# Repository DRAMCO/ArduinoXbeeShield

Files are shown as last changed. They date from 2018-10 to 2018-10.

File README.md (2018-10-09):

# Arduino Xbee Shield by [DRAMCO](www.dramco.be)

## Required Hardware

- Xbee module
- [Digi XBee interface board](https://www.digi.com/products/models/xbib-u-dev)
- Arduino Uno
- DRAMCO XBee Shield

## Getting Started Guide

1. Install [XCTU](https://www.digi.com/products/xbee-rf-solutions/xctu-software/xctu).
2. Connect the XBee module to the [Digi interface board](https://www.digi.com/products/models/xbib-u-dev)
3. Open XCTU and connect to the interface board
4. Configure the XBee module as required. For instance, set the `AP` parameter to API enabled with PPP.
5. Connect the XBee module to the shield
6. Connectthe shield to an Arduino UNO
7. Open your favourite Arduino IDE and download an XBee library. For example [this one](https://github.com/andrewrapp/xbee-arduino).
8. Start designing cool stuff!

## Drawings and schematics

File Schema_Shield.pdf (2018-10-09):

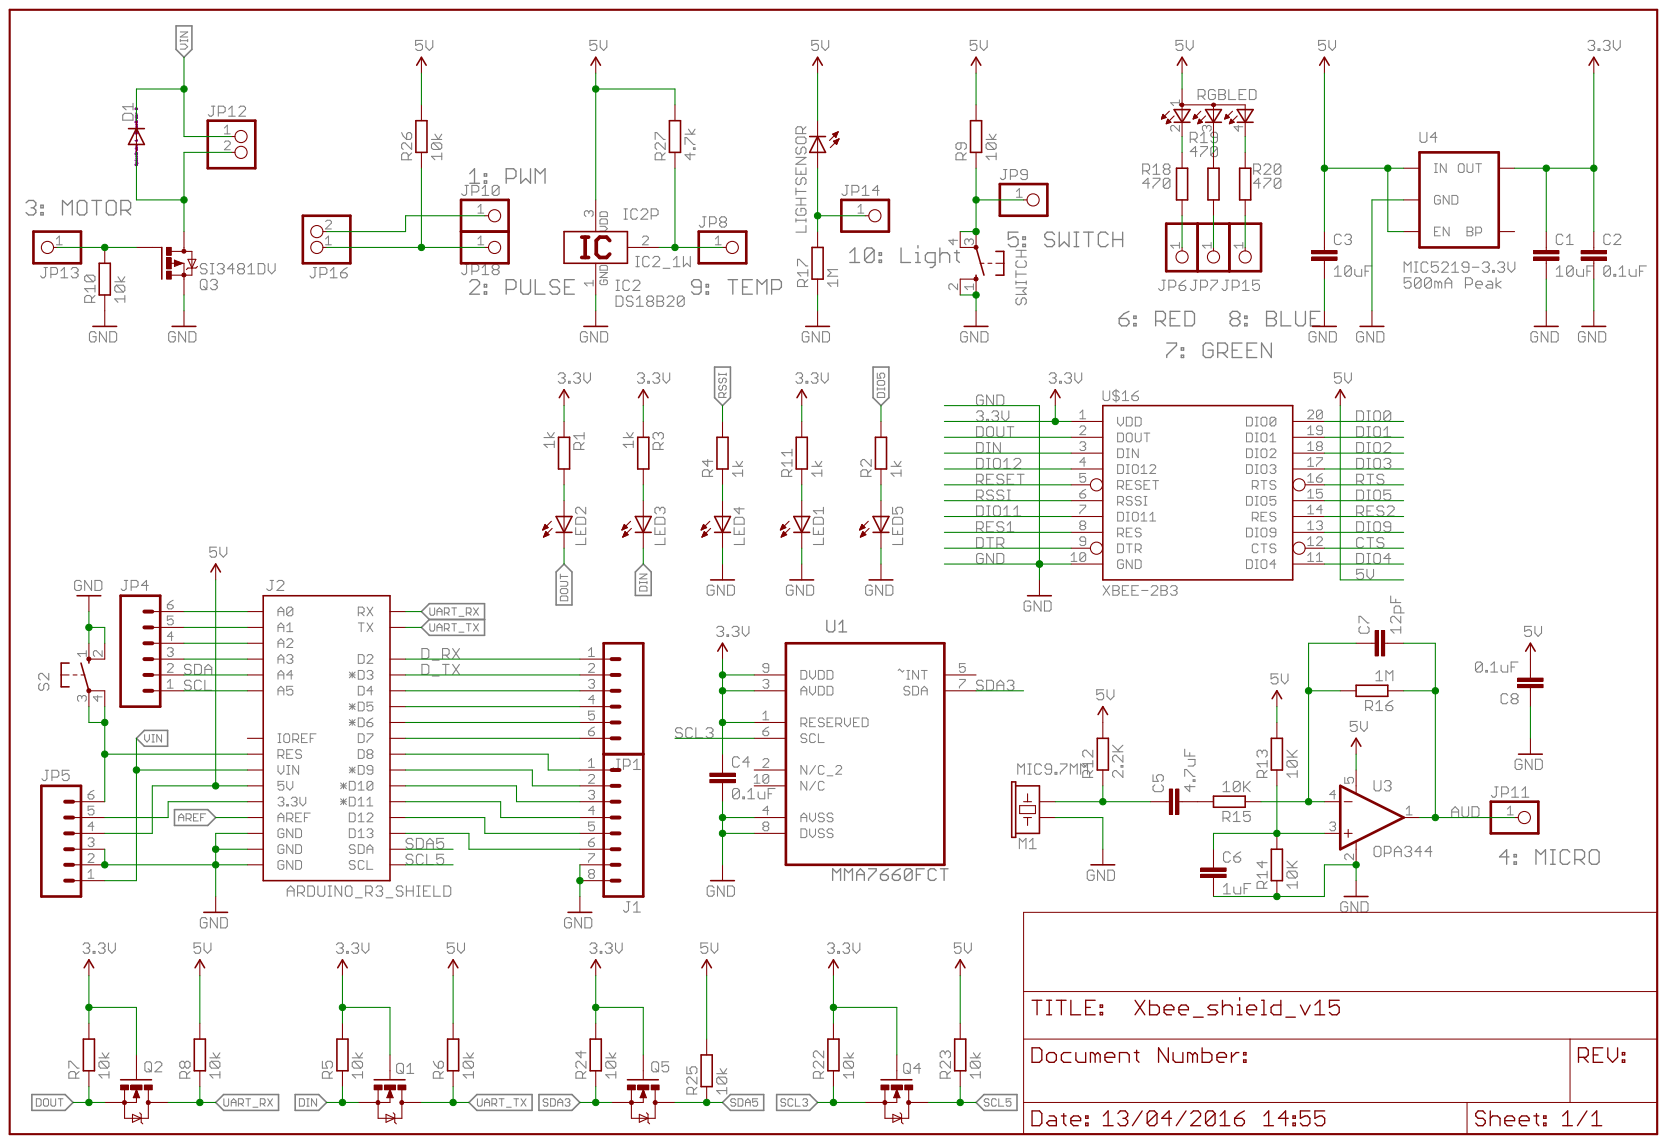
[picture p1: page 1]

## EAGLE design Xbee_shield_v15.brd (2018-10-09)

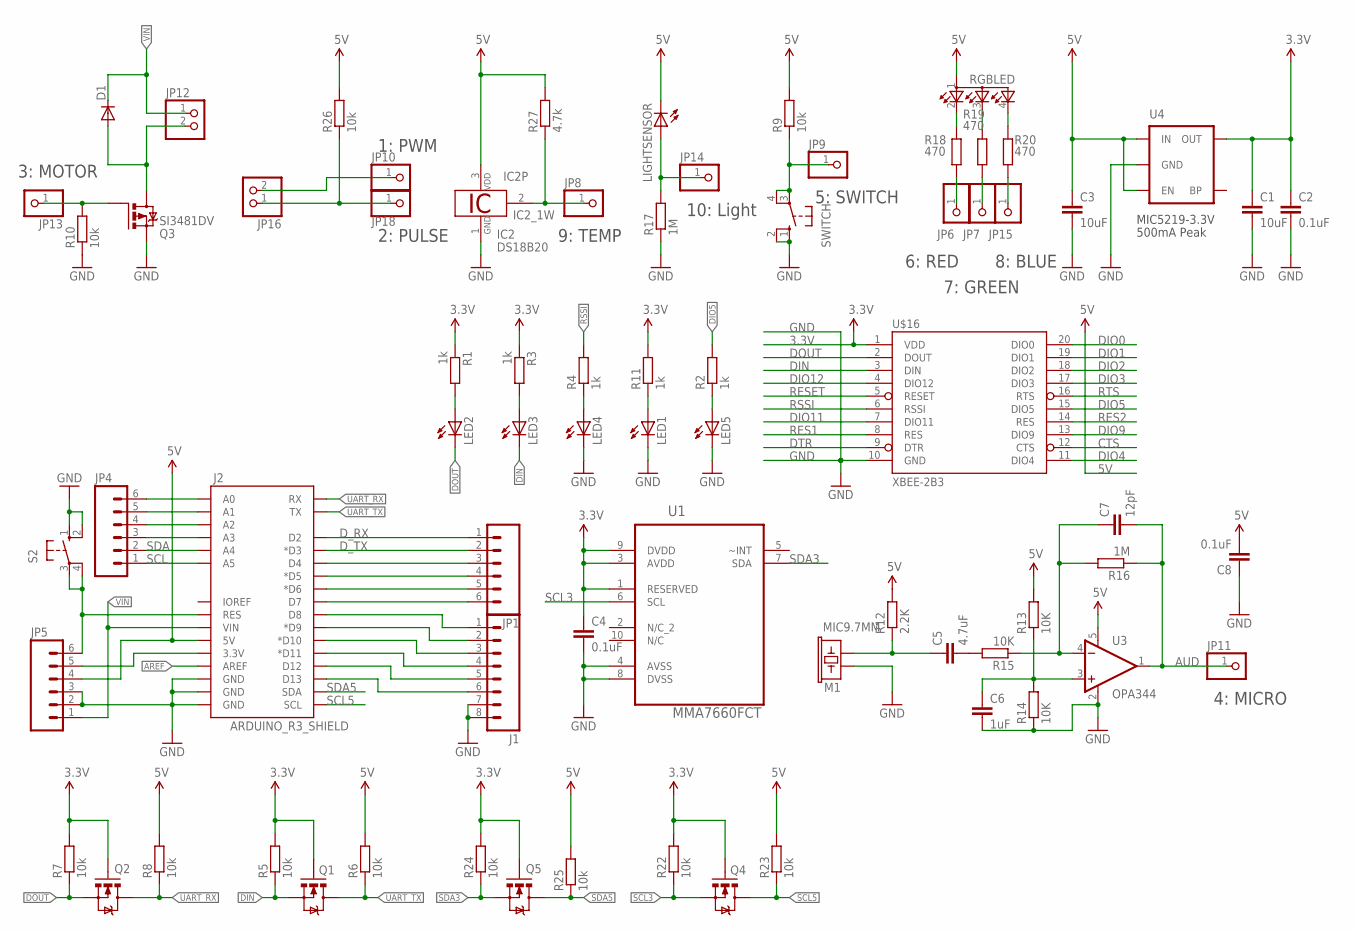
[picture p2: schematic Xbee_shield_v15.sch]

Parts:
C1, C3: 10uF; C0805
C2, C4, C8: 0.1uF; C0805
C5: 4.7uF; C0805
C6: 1uF; C0805
C7: 12pF; C0805
D1: DIODE-DO214AA; DO214AA
IC2: DS18B20; TO92-
J1: M08; 1X08_ROUND
J2: ARDUINO_R3_SHIELD; UNO_R3_SHIELD
JP1, JP4, JP5: M06SIP; 1X06
JP6, JP7, JP8, JP9, JP10, JP11, JP13, JP14, JP15, JP18: PINHD-1X1; 1X01
JP12, JP16: PINHD-1X2; 1X02
LED1, LED2, LED3, LED4, LED5: LEDCHIPLED_0805; CHIPLED_0805
LIGHTSENSOR: LED5MM
M1: MIC9.7MM; MIC-9.7MM
Q1, Q2, Q4, Q5: MOSFET-NCHANNELSMD; SOT23-3
Q3: SI3481DV; TSOP-6.PAC
R1, R2, R3, R4, R11: 1k; R0805
R5, R6, R7, R8, R9, R10, R22, R23, R24, R25, R26: 10k; R0805
R12: 2.2K; R0805
R13, R14, R15: 10K; R0805
R16, R17: 1M; R0805
R18, R19, R20: 470; R0805
R27: 4.7k; R0805
RGBLED: TOPLED-3; P-LCC-4-3
S2: 10-XX; B3F-10XX
SWITCH: 10-XX; B3F-10XX
U1: MMA7660FCT; DFN300X300X100-10N
U3: OPA344; SOT23-5
U4: V_REG_LDOSMD; SOT23-5
U$16: XBEE-2B3; XBEE-SMD

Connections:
3.3V: C1.1, C2.1, C4.1, Q1.1 (G), Q2.1 (G), Q4.1 (G), Q5.1 (G), R1.1, R3.1, R5.2, R7.2, R11.2, R22.2, R24.2, U1.1 (RESERVED), U1.3 (AVDD), U1.9 (DVDD), U4.5 (OUT), U$16.1 (VDD)
5V: C3.1, C8.2, IC2.3 (VDD), J2.5V, JP5.4, LIGHTSENSOR.K (C), R6.2, R8.2, R9.2, R12.2, R13.2, R23.2, R25.2, R26.2, R27.2, RGBLED.1 (A2), U3.5 (V+), U4.1 (IN), U4.3 (EN)
AREF: J2.AREF
AUD: C7.2, JP11.1, R16.1, U3.1 (OUT)
CTS: U$16.12 (CTS)
DIN: LED3.C, Q1.2 (S), R5.1, U$16.3 (DIN)
DIO0: U$16.20 (DIO0)
DIO1: U$16.19 (DIO1)
DIO2: U$16.18 (DIO2)
DIO3: U$16.17 (DIO3)
DIO4: U$16.11 (DIO4)
DIO5: R2.2, U$16.15 (DIO5)
DIO9: U$16.13 (DIO9)
DIO11: U$16.7 (DIO11)
DIO12: U$16.4 (DIO12)
DOUT: LED2.C, Q2.2 (S), R7.1, U$16.2 (DOUT)
DTR: U$16.9 (DTR)
D_RX: J2.D2, JP1.1
D_TX: J2.D3 (*D3), JP1.2
GND: C1.2, C2.2, C3.2, C4.2, C6.2, C8.1, IC2.1 (GND), J1.7, J1.8, J2.GND@0 (GND), J2.GND@1 (GND), J2.GND@2 (GND), JP5.2, JP5.3, LED1.C, LED4.C, LED5.C, M1.2, Q3.4 (S), R10.1, R14.1, R17.1, S2.1 (S), S2.2 (S1), SWITCH.1 (S), SWITCH.2 (S1), U1.4 (AVSS), U1.8 (DVSS), U3.2 (V-), U4.2 (GND), U$16.10 (GND)
unnamed: LED2.A, R1.2
unnamed: LED4.A, R4.1
unnamed: J1.6, J2.D13
unnamed: LED3.A, R3.2
unnamed: J2.A0, JP4.6
unnamed: J2.A1, JP4.5
unnamed: J2.A2, JP4.4
unnamed: J2.RES, JP5.6, S2.3, S2.4 (P1)
unnamed: JP9.1, R9.1, SWITCH.3, SWITCH.4 (P1)
unnamed: IC2.2 (1W), JP8.1, R27.1
unnamed: JP10.1, JP16.2
unnamed: C5.1, M1.1, R12.1
unnamed: C7.1, R15.1, R16.2, U3.4 (-IN)
unnamed: C5.2, R15.2
unnamed: C6.1, R13.1, R14.2, U3.3 (+IN)
unnamed: J1.1, J2.D8
unnamed: J1.2, J2.D9 (*D9)
unnamed: JP13.1, Q3.3 (G), R10.2
unnamed: D1.A, JP12.2, Q3.1 (D), Q3.2 (D), Q3.5 (D), Q3.6 (D)
unnamed: JP14.1, LIGHTSENSOR.A, R17.2
unnamed: J2.A3, JP4.3
unnamed: JP16.1, JP18.1, R26.1
unnamed: J2.3.3V, JP5.5
unnamed: R18.2, RGBLED.2 (CRED)
unnamed: R19.2, RGBLED.3 (CBLUE)
unnamed: R20.2, RGBLED.4 (CGREEN)
unnamed: JP6.1, R18.1
unnamed: J1.3, J2.D10 (*D10)
unnamed: JP7.1, R19.1
unnamed: JP15.1, R20.1
unnamed: LED1.A, R11.1
unnamed: J1.4, J2.D11 (*D11)
unnamed: J1.5, J2.D12
unnamed: LED5.A, R2.1
unnamed: J2.D4, JP1.3
unnamed: J2.D5 (*D5), JP1.4
unnamed: J2.D6 (*D6), JP1.5
unnamed: J2.D7, JP1.6
RES1: U$16.8 (RES)
RES2: U$16.14 (RES)
RESET: U$16.5 (RESET)
RSSI: R4.2, U$16.6 (RSSI)
RTS: U$16.16 (RTS)
SCL: J2.A5, JP4.1
SCL3: Q4.2 (S), R22.1, U1.6 (SCL)
SCL5: J2.SCL, Q4.3 (D), R23.1
SDA: J2.A4, JP4.2
SDA3: Q5.2 (S), R24.1, U1.7 (SDA)
SDA5: J2.SDA, Q5.3 (D), R25.1
UART_RX: J2.RX, Q2.3 (D), R8.1
UART_TX: J2.TX, Q1.3 (D), R6.1
VIN: D1.C, J2.VIN, JP5.1, JP12.1

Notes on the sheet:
500mA Peak
MIC5219-3.3V
1: PWM
2: PULSE
3: MOTOR
10: Light
5: SWITCH
6: RED
7: GREEN
8: BLUE
9: TEMP
4: MICRO

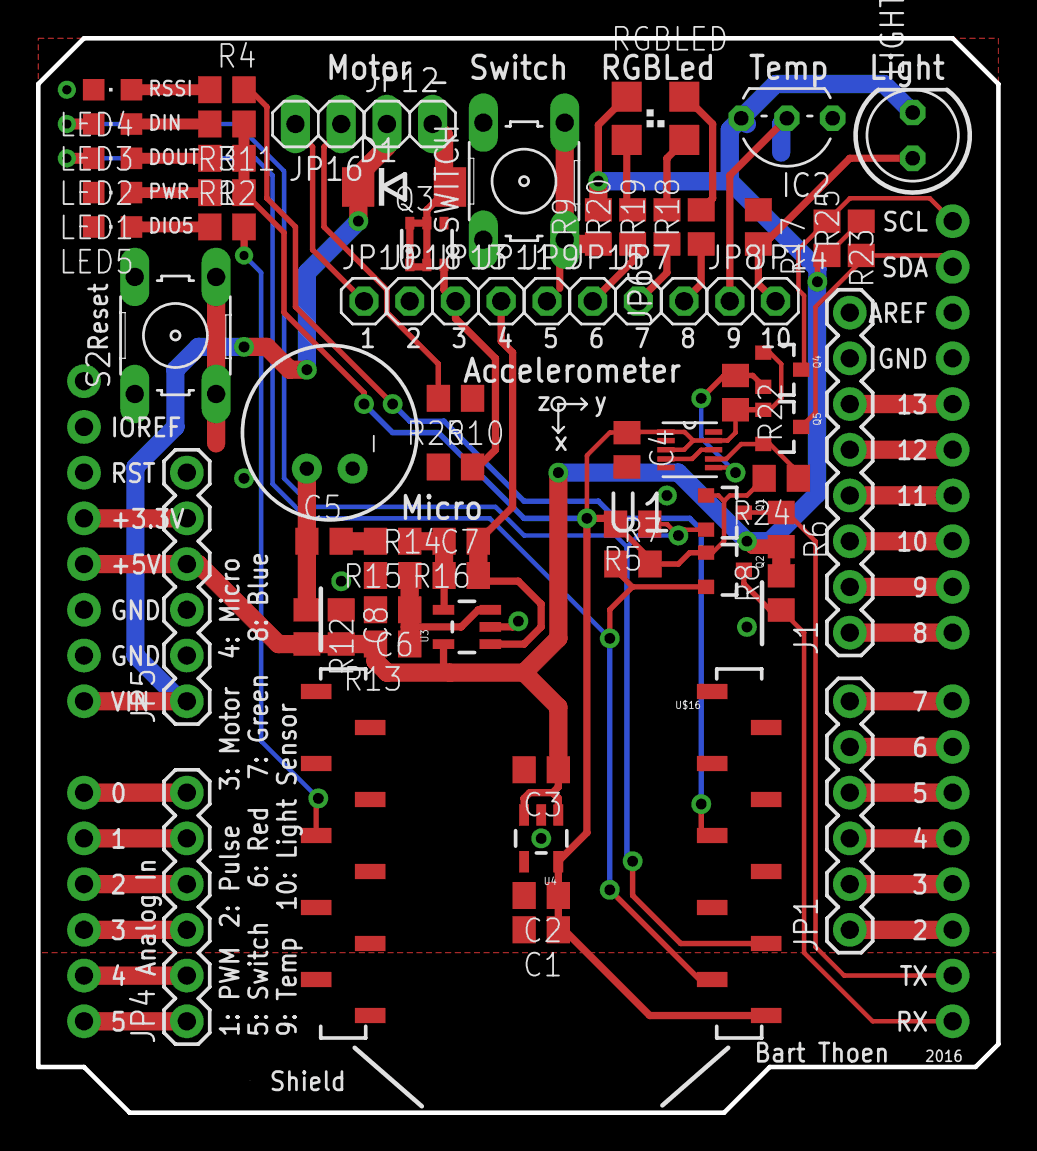
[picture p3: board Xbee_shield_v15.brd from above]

Board: 2 copper layers, 53.3 x 59.7 mm, 72 parts (1 on the bottom side), 57 nets.

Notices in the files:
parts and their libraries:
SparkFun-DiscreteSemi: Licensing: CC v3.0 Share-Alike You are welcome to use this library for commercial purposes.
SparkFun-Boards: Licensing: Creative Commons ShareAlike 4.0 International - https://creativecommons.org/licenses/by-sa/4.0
